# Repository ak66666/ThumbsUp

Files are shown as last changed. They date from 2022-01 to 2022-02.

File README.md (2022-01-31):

# 44 Keys Board "Thumbs Up!"

44-key Split Keyboard PCB with the thumb keys placed on the raised platforms.

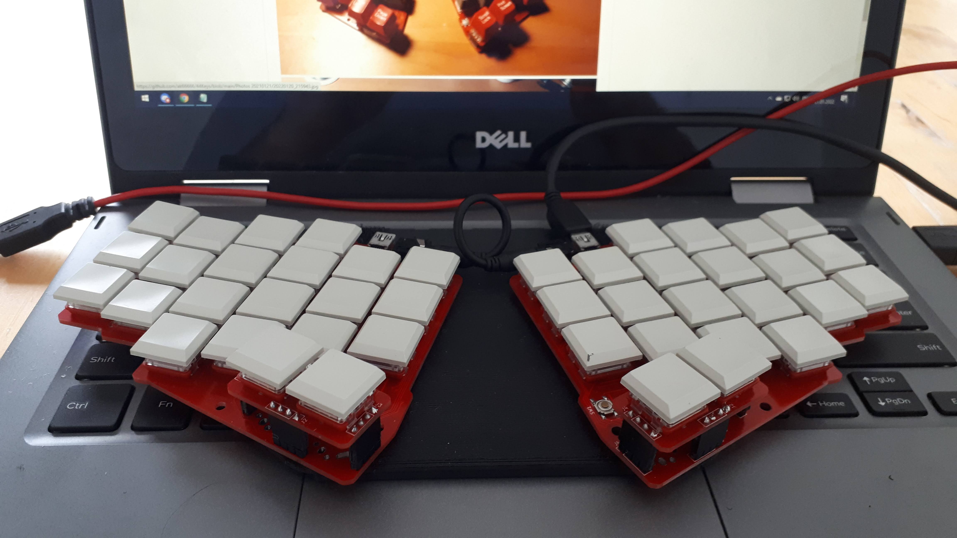
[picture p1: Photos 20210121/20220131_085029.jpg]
Kailh Choc

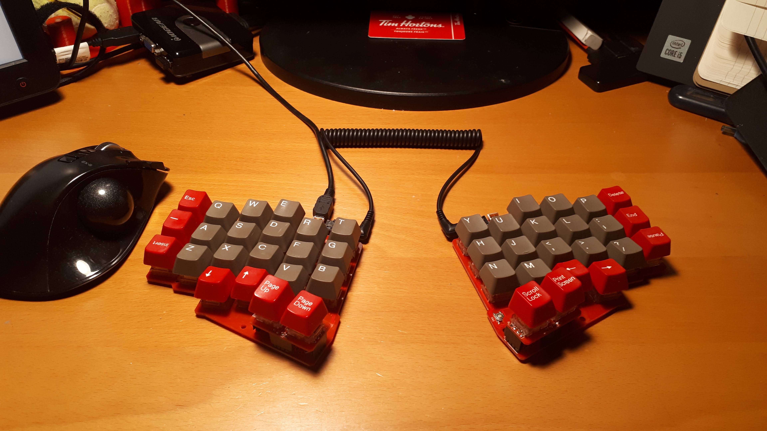
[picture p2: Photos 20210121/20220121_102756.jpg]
Matias


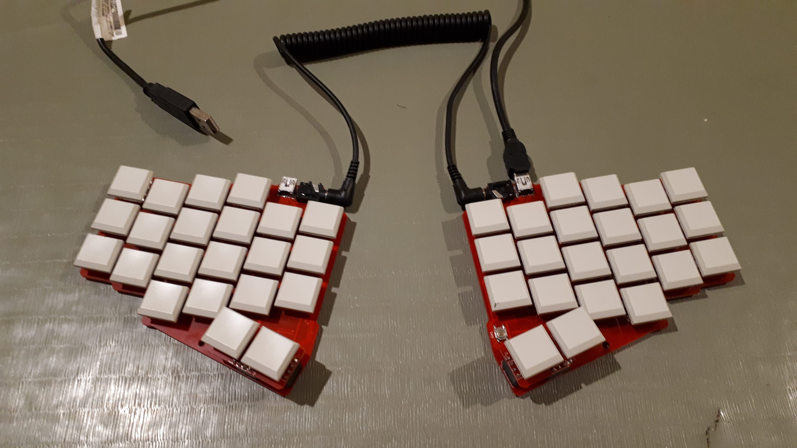
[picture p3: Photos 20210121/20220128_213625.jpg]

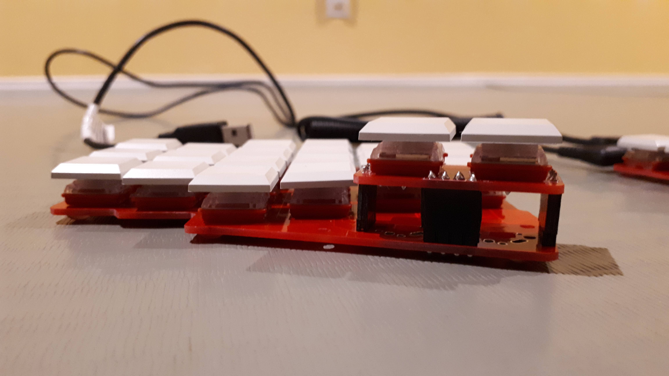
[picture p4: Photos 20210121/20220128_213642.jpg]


Ideas behind this design and layout are described here:


The naked PCB approach is borrowed from Georgi created by Germ @GBoards.ca

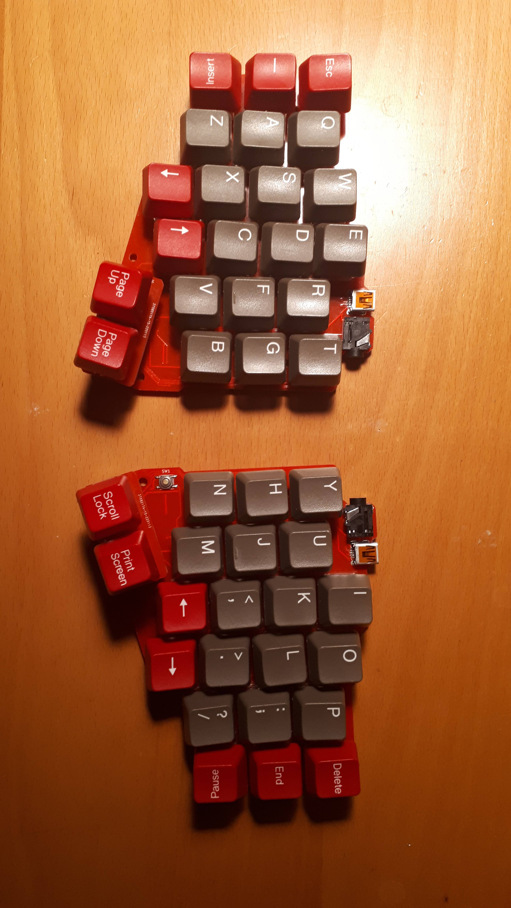
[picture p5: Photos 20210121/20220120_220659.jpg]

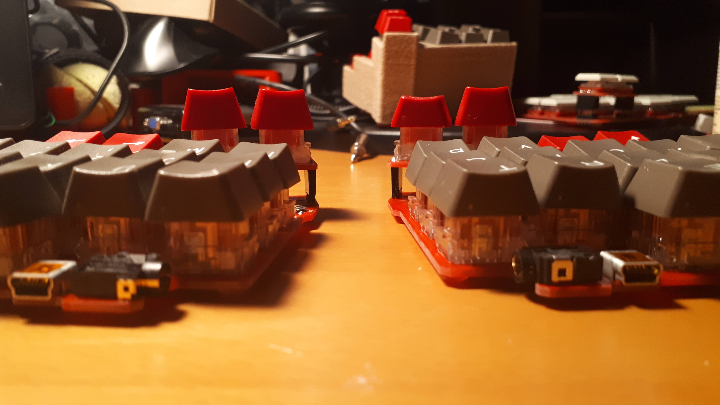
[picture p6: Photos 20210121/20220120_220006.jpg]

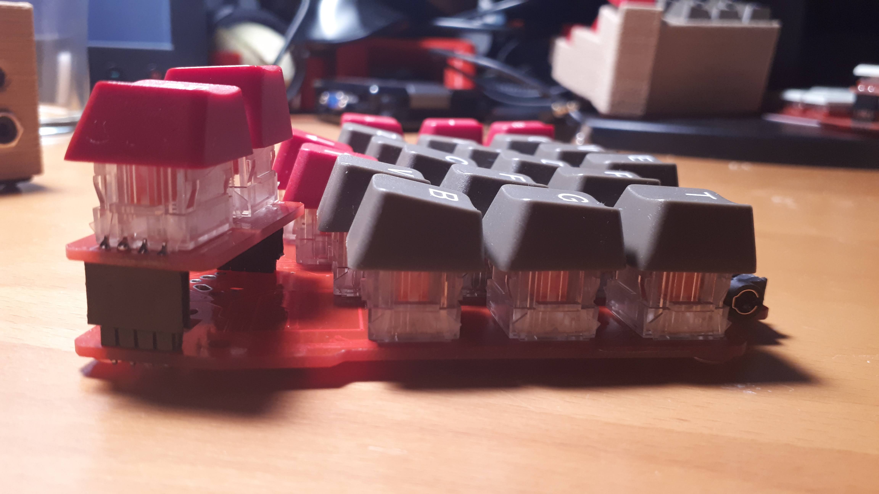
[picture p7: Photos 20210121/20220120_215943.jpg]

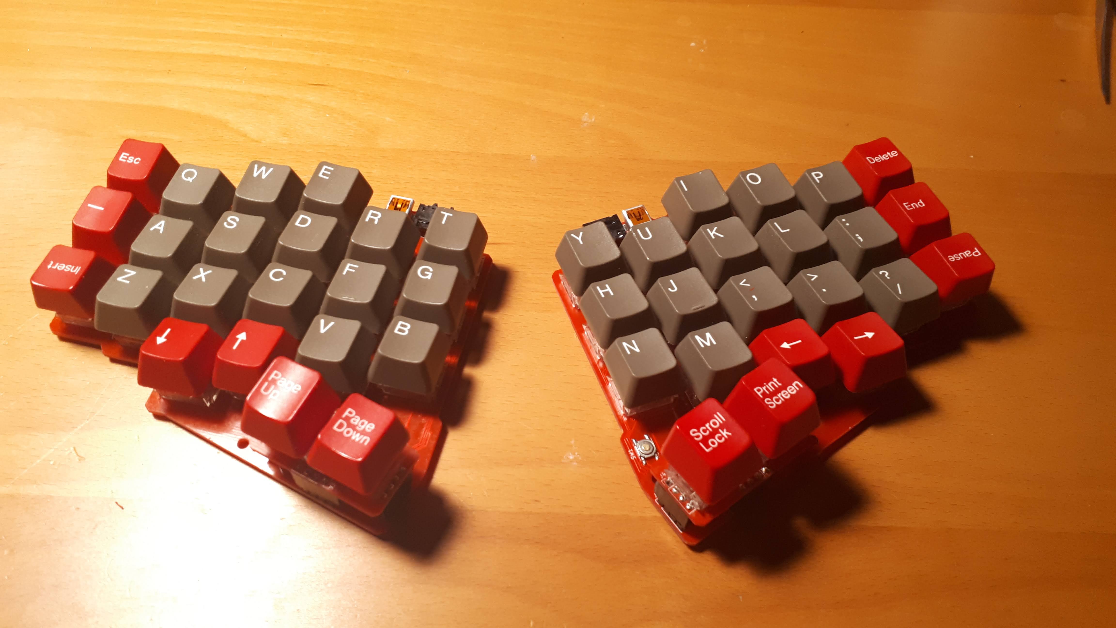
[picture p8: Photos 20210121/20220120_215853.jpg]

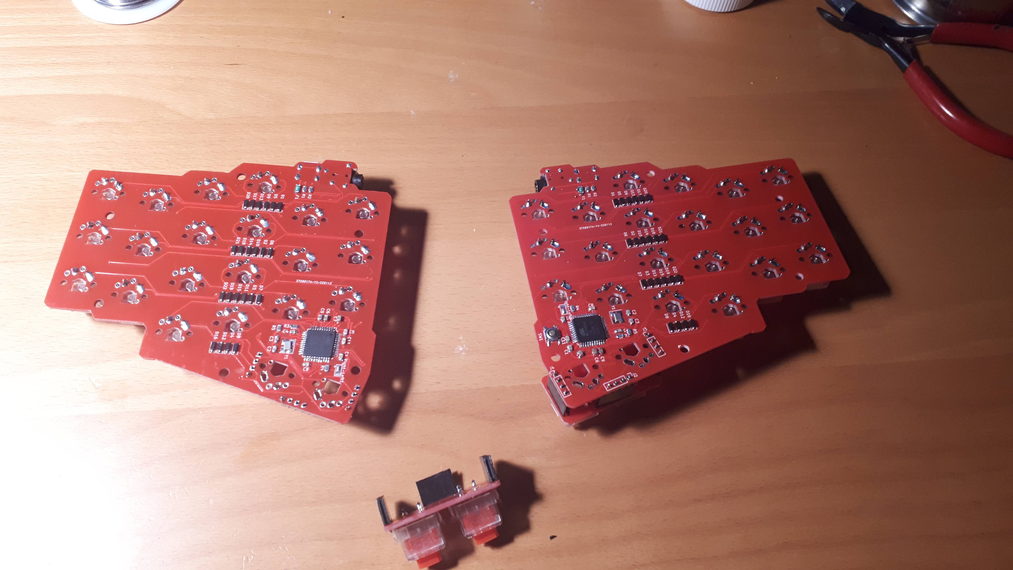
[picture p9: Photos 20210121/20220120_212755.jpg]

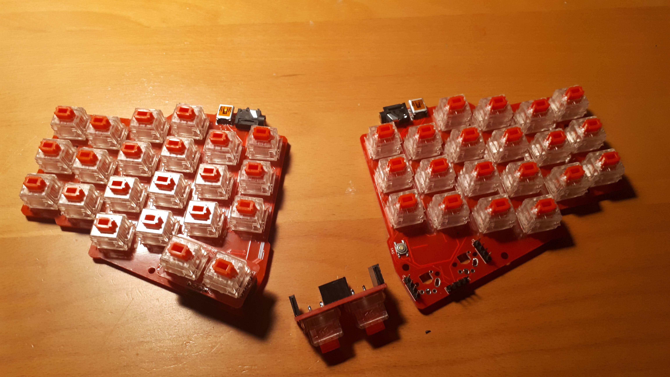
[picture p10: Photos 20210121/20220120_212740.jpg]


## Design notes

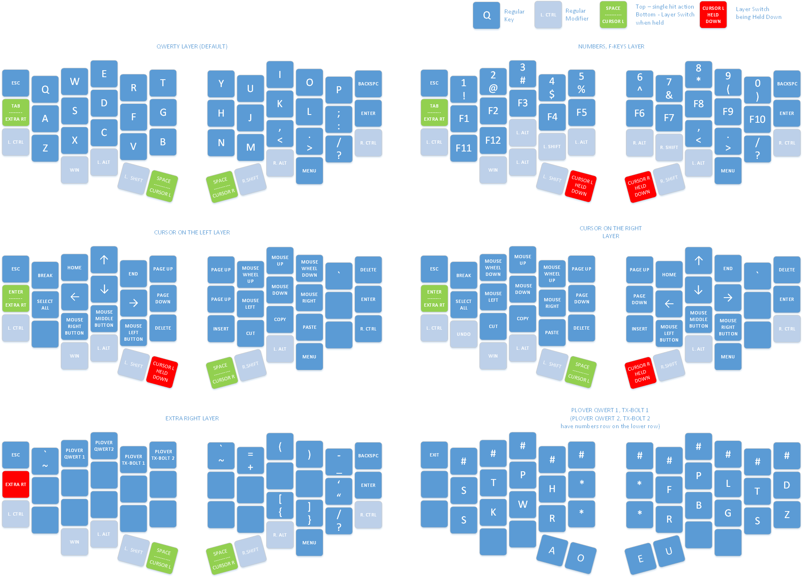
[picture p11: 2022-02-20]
Photos 20210121/44 Key Keyboard Layout.png

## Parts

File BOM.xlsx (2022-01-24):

Component | Quantity per side | Package | Sample Part | On hand | Soldered/Recoverable | Total | Qty Needed | To buy
Ceramic Capacitor, 0.1uF | 5 | 805 | 1276-2450-1-ND (https://www.digikey.com/product-detail/en/samsung-electro-mechanics/CL21B104MBCNNNC/1276-2450-1-ND/3890536) | 0 | 8 | 8 | 10 | 2
Ceramic Capacitor, 10uF | 1 | 805 | 1276-6455-1-ND (https://www.digikey.com/product-detail/en/samsung-electro-mechanics/CL21A106KOQNNNG/1276-6455-1-ND/5958083) | 5 | 1 | 6 | 2 | -4
Ceramic Capacitor, 1uF | 2 | 805 | 1276-1066-1-ND (https://www.digikey.com/product-detail/en/samsung-electro-mechanics/CL21B105KAFNNNE/1276-1066-1-ND/3889152) | 1 | 2 | 3 | 4 | 1
Ceramic Capacitor, 22pF | 2 | 805 | 1276-2605-1-ND (https://www.digikey.com/product-detail/en/samsung-electro-mechanics/CL21C220JB61PNC/1276-2605-1-ND/3890691) | 13 | 4 | 17 | 4 | -13
Diode, Generic | 22 | SOD-123 | 1N4148WTPMSCT-ND (https://www.digikey.com/product-detail/en/micro-commercial-co/1N4148W-TP/1N4148WTPMSCT-ND/717311) | 144 | 22 | 166 | 44 | -122
Polyfuse, 500mA hold, 1A trip | 1 | 1206 | 507-1803-1-ND (https://www.digikey.com/product-detail/en/bel-fuse-inc/0ZCJ0050AF2E/507-1803-1-ND/4156312) | 7 |  | 7 | 2 | -5
Resistor, 10k | 2 | 805 | P10KDACT-ND (https://www.digikey.com/product-detail/en/panasonic-electronic-components/ERA-6AEB103V/P10KDACT-ND/1465971) | 12 | 4 | 16 | 4 | -12
Resistor, 22 | 2 | 805 | P22ACT-ND (https://www.digikey.com/product-detail/en/panasonic-electronic-components/ERJ-6GEYJ220V/P22ACT-ND/87316) | 12 | 4 | 16 | 4 | -12
Low Profile Tactile Switch | 1 | 5.2x5.2mm | CKN10361CT-ND (https://www.digikey.com/product-detail/en/c-k/RS-187R05A2-DS-MT-RT/CKN10361CT-ND/2747199) | 5 | 2 | 7 | 2 | -5
ATMEGA32U4 Microcontroller | 1 | 44TQFP 10x10mm | ATMEGA32U4-AU-ND (https://www.digikey.com/product-detail/en/microchip-technology/ATMEGA32U4-AU/ATMEGA32U4-AU-ND/1914602) | 9 | 3 | 12 | 2 | -10
Molex Mini-B USB C Receptacle | 1 | Molex-0548190589 | WM3895CT-ND (https://www.digikey.com/product-detail/en/molex-llc/0548190589/WM3895CT-ND/2421963) | 6 | 2 | 8 | 2 | -6
Crystal, 16MHz | 1 | 3.2x2.5mm, 4 pad | 1253-1698-1-ND‎ (https://www.digikey.com/product-detail/en/CX3225SB16000D0GZJC1/1253-1698-1-ND/5995245/?itemSeq=264931473) | 6 | 1 | 7 | 2 | -5
Stereo Jack 3.5 mm | 1 |  | SJ-43515TS | 6 | 2 | 8 | 2 | -6
Halves to build | 2

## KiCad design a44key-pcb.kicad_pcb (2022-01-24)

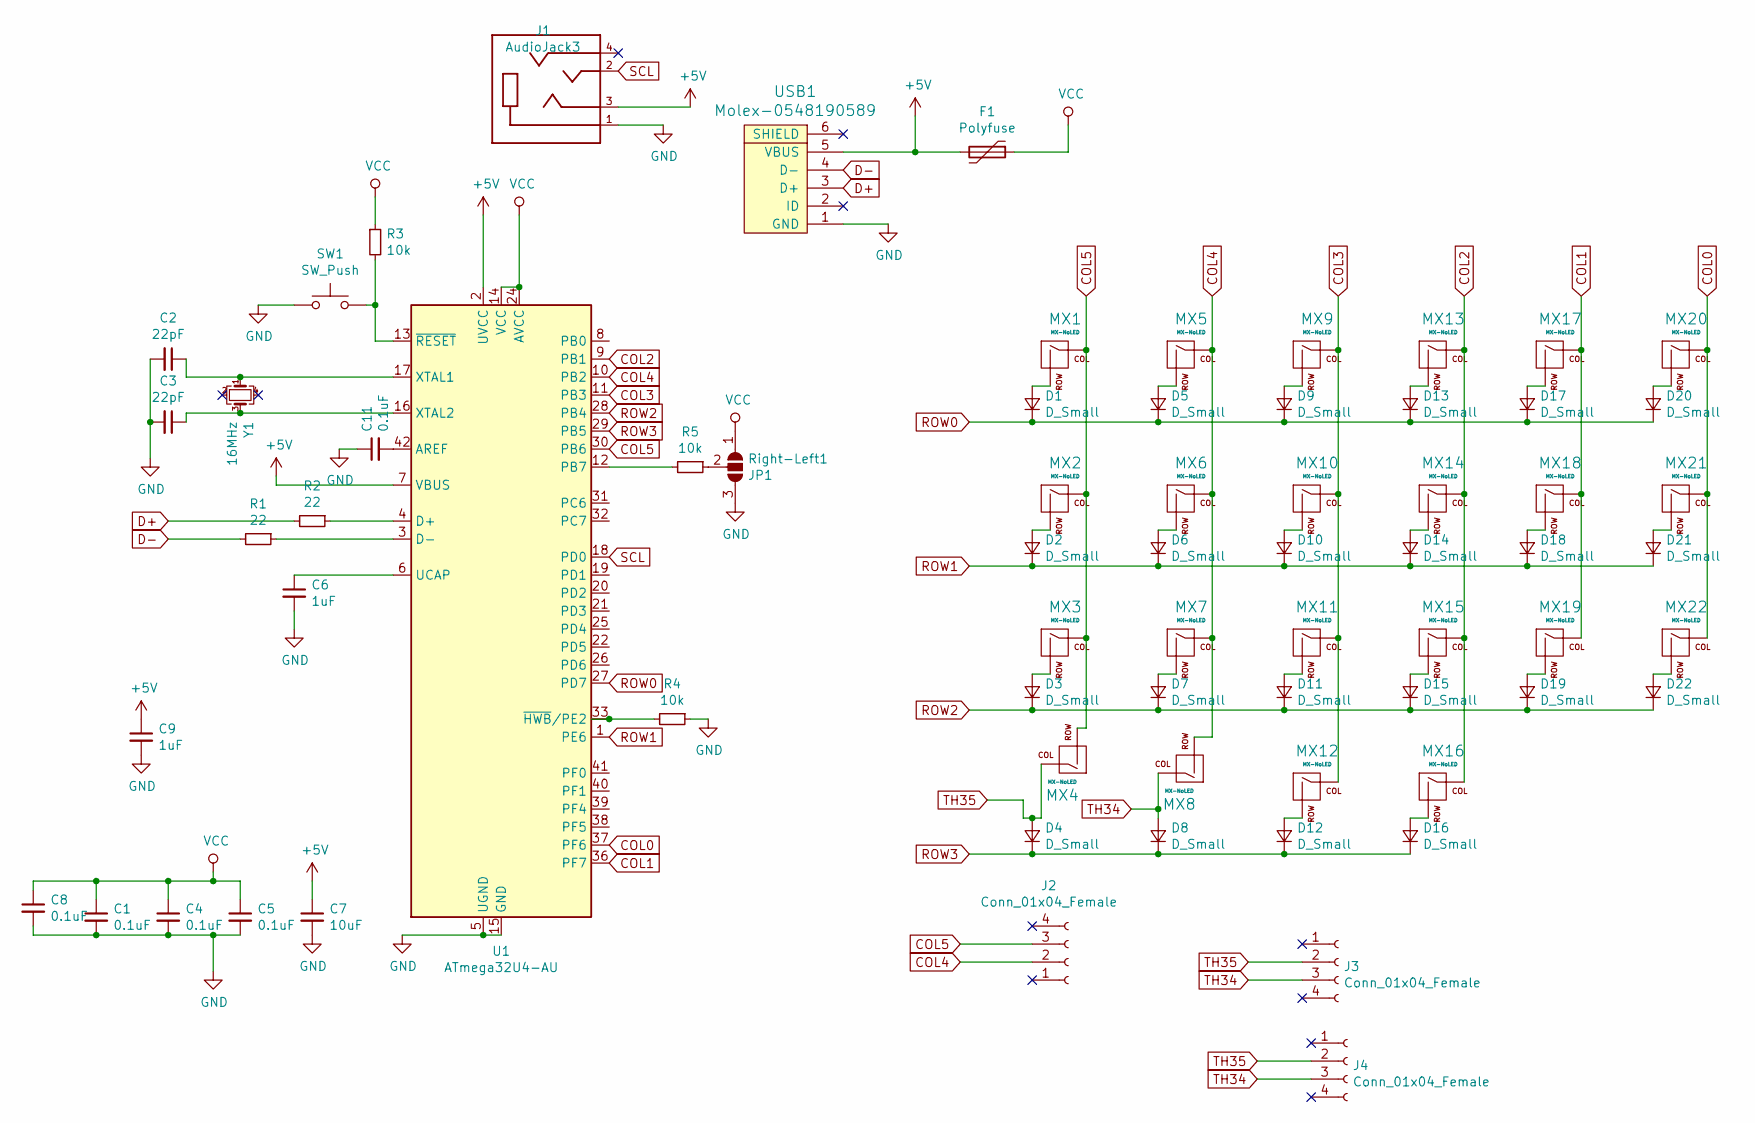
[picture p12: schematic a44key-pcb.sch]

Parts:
C1, C4, C5, C8, C11: 0.1uF; C_0805_2012Metric
C2, C3: 22pF; C_0805_2012Metric
C6, C9: 1uF; C_0805_2012Metric
C7: 10uF; C_0805_2012Metric
D1, D2, D3, D4, D5, D6, D7, D8, D9, D10, D11, D12, D13, D14, D15, D16, D17, D18, D19, D20, D21, D22: D_Small; D_SOD-123
F1: Polyfuse; Fuse_1206_3216Metric
J1: AudioJack3; CUI_SJ-43514
J2, J3, J4: Conn_01x04_Female; PinHeader_1x04_P2.54mm_Vertical
MX1, MX2, MX3, MX4, MX5, MX6, MX7, MX8, MX9, MX10, MX11, MX12, MX13, MX14, MX15, MX16, MX17, MX18, MX19, MX20, MX21, MX22: MX-NoLED; MX-Alps-Choc-X-1U-NoLED
R1, R2: 22; R_0805_2012Metric
R3, R4, R5: 10k; R_0805_2012Metric
Right-Left1: JP1; SolderJumper-3_P1.3mm_Open_Pad1.0x1.5mm
SW1: SW_Push; SKQG-1155865
U1: ATmega32U4-AU; TQFP-44_10x10mm_P0.8mm
USB1: Molex-0548190589
Y1: 16MHz; Crystal_SMD_3225-4Pin_3.2x2.5mm_HandSoldering

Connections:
+5V: C7.1, C9.1, F1.2, J1.3, U1.2 (UVCC), U1.7 (VBUS), USB1.5 (VBUS)
COL0: MX20.1 (COL), MX21.1 (COL), MX22.1 (COL), U1.37 (PF6)
COL1: MX17.1 (COL), MX18.1 (COL), MX19.1 (COL), U1.36 (PF7)
COL2: MX13.1 (COL), MX14.1 (COL), MX15.1 (COL), MX16.1 (COL), U1.9 (PB1)
COL3: MX9.1 (COL), MX10.1 (COL), MX11.1 (COL), MX12.1 (COL), U1.11 (PB3)
COL4: J2.2, MX5.1 (COL), MX6.1 (COL), MX7.1 (COL), MX8.2 (ROW), U1.10 (PB2)
COL5: J2.3, MX1.1 (COL), MX2.1 (COL), MX3.1 (COL), MX4.2 (ROW), U1.30 (PB6)
D+: R2.2, USB1.3 (D+)
D-: R1.2, USB1.4 (D-)
GND: C1.2, C2.2, C3.2, C4.2, C5.2, C6.2, C7.2, C8.2, C9.2, C11.1, J1.1, R4.1, Right-Left1.3 (B), SW1.1, U1.5 (UGND), U1.15 (GND), U1.23 (GND), U1.35 (GND), U1.43 (GND), USB1.1 (GND)
unnamed: C2.1, U1.17 (XTAL1), Y1.1
unnamed: C3.1, U1.16 (XTAL2), Y1.3
unnamed: C6.1, U1.6 (UCAP)
unnamed: C11.2, U1.42 (AREF)
unnamed: D1.2 (A), MX1.2 (ROW)
unnamed: D2.2 (A), MX2.2 (ROW)
unnamed: D3.2 (A), MX3.2 (ROW)
unnamed: D5.2 (A), MX5.2 (ROW)
unnamed: D6.2 (A), MX6.2 (ROW)
unnamed: D7.2 (A), MX7.2 (ROW)
unnamed: D9.2 (A), MX9.2 (ROW)
unnamed: D10.2 (A), MX10.2 (ROW)
unnamed: D11.2 (A), MX11.2 (ROW)
unnamed: D12.2 (A), MX12.2 (ROW)
unnamed: D13.2 (A), MX13.2 (ROW)
unnamed: D14.2 (A), MX14.2 (ROW)
unnamed: D15.2 (A), MX15.2 (ROW)
unnamed: D16.2 (A), MX16.2 (ROW)
unnamed: D17.2 (A), MX17.2 (ROW)
unnamed: D18.2 (A), MX18.2 (ROW)
unnamed: D19.2 (A), MX19.2 (ROW)
unnamed: D20.2 (A), MX20.2 (ROW)
unnamed: D21.2 (A), MX21.2 (ROW)
unnamed: D22.2 (A), MX22.2 (ROW)
unnamed: R1.1, U1.3 (D-)
unnamed: R2.1, U1.4 (D+)
unnamed: R3.2, SW1.2, U1.13 (~RESET)
unnamed: R4.2, U1.33 (~HWB~/PE2)
unnamed: R5.1, Right-Left1.2 (C)
unnamed: R5.2, U1.12 (PB7)
ROW0: D1.1 (K), D5.1 (K), D9.1 (K), D13.1 (K), D17.1 (K), D20.1 (K), U1.27 (PD7)
ROW1: D2.1 (K), D6.1 (K), D10.1 (K), D14.1 (K), D18.1 (K), D21.1 (K), U1.1 (PE6)
ROW2: D3.1 (K), D7.1 (K), D11.1 (K), D15.1 (K), D19.1 (K), D22.1 (K), U1.28 (PB4)
ROW3: D4.1 (K), D8.1 (K), D12.1 (K), D16.1 (K), U1.29 (PB5)
SCL: J1.2, U1.18 (PD0)
TH34: D8.2 (A), J3.3, J4.3, MX8.1 (COL)
TH35: D4.2 (A), J3.2, J4.2, MX4.1 (COL)
VCC: C1.1, C4.1, C5.1, C8.1, F1.1, R3.1, Right-Left1.1 (A), U1.14 (VCC), U1.24 (AVCC), U1.34 (VCC), U1.44 (AVCC)

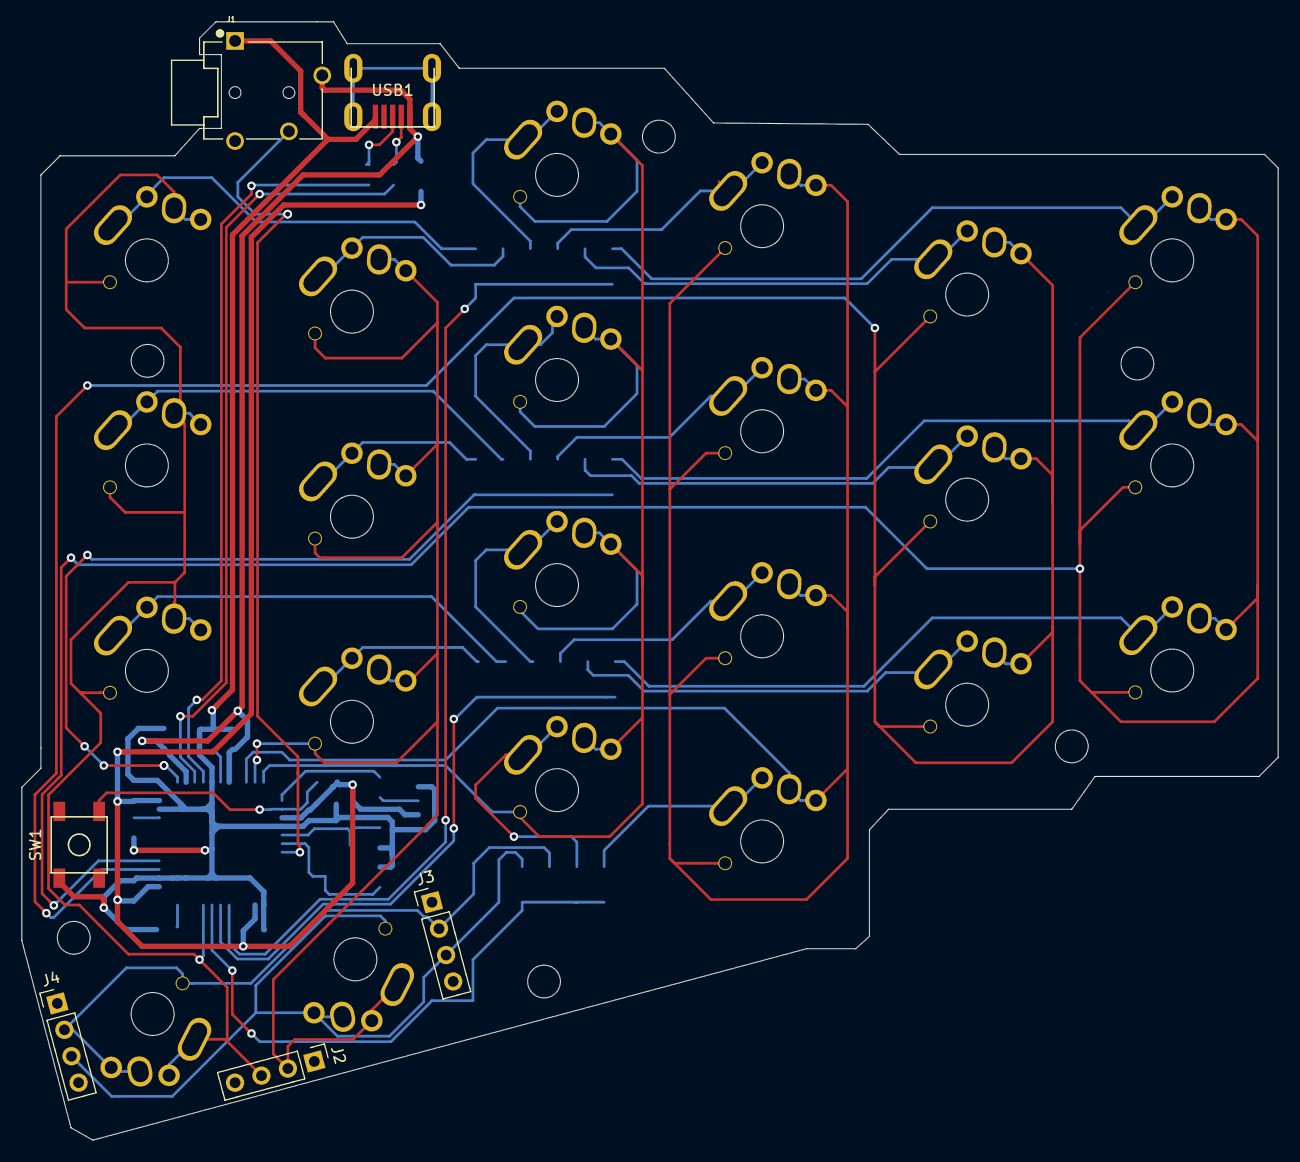
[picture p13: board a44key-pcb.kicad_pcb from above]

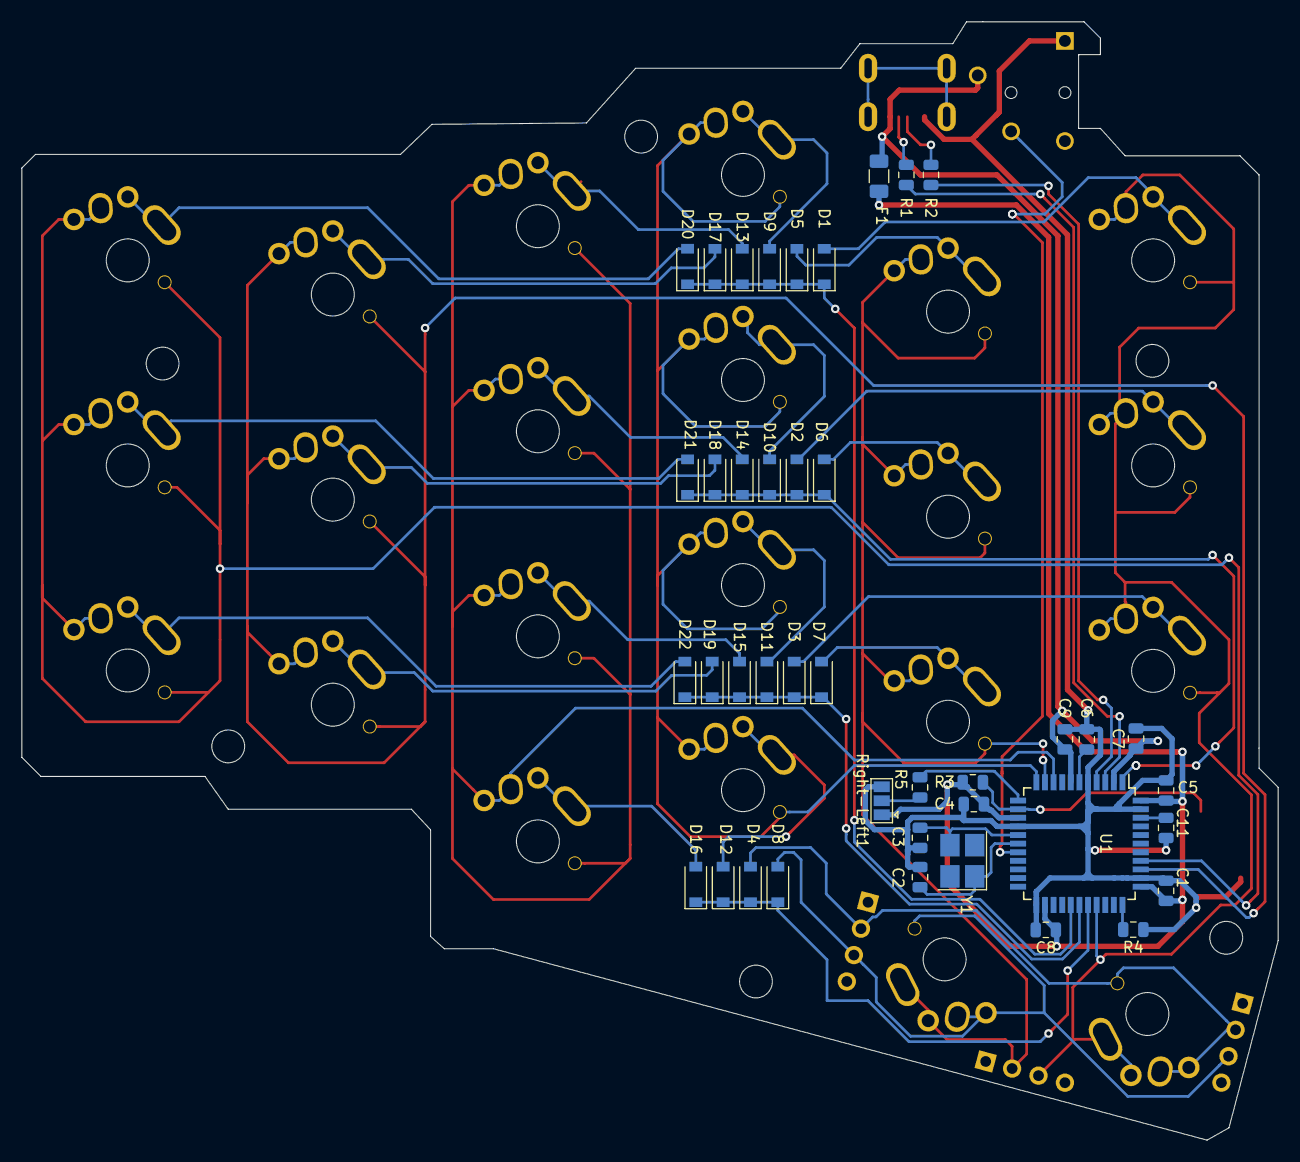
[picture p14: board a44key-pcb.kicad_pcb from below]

Board: 2 copper layers, 116.7 x 103.9 mm, 69 parts (41 on the bottom side), 48 nets.

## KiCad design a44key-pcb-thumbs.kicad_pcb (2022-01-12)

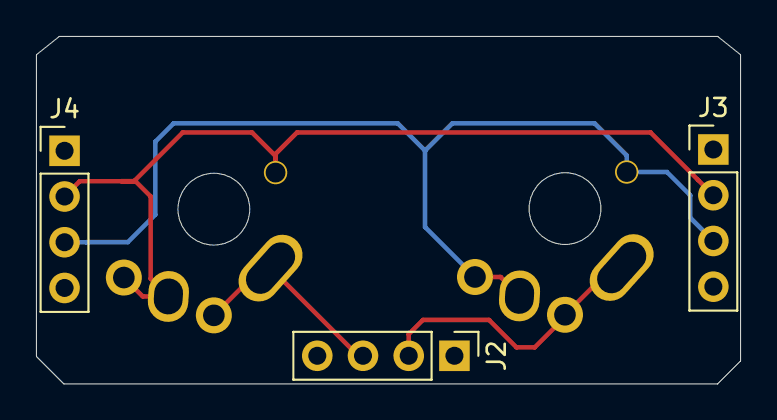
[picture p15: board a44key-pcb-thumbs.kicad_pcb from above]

Board: 2 copper layers, 39.1 x 19.3 mm, 5 parts (0 on the bottom side), 4 nets.

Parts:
J2, J3, J4: Conn_01x04_Female; PinHeader_1x04_P2.54mm_Vertical
MX4, MX8: MX-NoLED; MX-Alps-Choc-X-1U-NoLED

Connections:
COL4: J2.2, MX8.2
COL5: J2.3, MX4.2
TH34: J3.3, J4.3, MX8.1
TH35: J3.2, J4.2, MX4.1

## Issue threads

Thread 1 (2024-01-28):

STL for ThumbsUp! v2 "lift"

BigBlueHat, 2024-01-28:
There used to be an STL file on the thumbsup.shop site (which seems to currently be down) for tilting/lifting the ThumbsUp! v2 forward.

Could it be added to this repo?

Thanks for the great keyboard, @ak66666!
🎩

ak66666, 2024-01-28:
Hi,
Thank you.
Please find them here:
https://www.thingiverse.com/ak666666/designs

Thank you,
Alexander (Sasha) Karmanov
289-952-3067

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

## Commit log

2021-10-16 KiCAD project added.
    KiCAD Project created
    [a44key-pcb.kicad_pcb, a44key-pcb.sch]
2021-10-16 Submodules added
    [a44key-pcb.sch]
2021-10-18 Somewhat ready
    [a44key-pcb-B_Cu.gbl, a44key-pcb-B_Mask.gbs, a44key-pcb-B_SilkS.gbo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]
2021-10-18 Gerbers created
    [a44key-pcb-B_Cu.gbl, a44key-pcb-B_Mask.gbs, a44key-pcb-B_SilkS.gbo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]
2021-10-22 Covered with zones
    [a44key-pcb.kicad_pcb, a44key-pcb.sch]
2021-10-22 Generated Gerbers
    [a44key-pcb-B_Cu.gbl, a44key-pcb-B_Mask.gbs, a44key-pcb-B_SilkS.gbo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]
2021-11-10 Added raisers for the thumbs
    [a44key-pcb.kicad_pcb, a44key-pcb.sch]
2021-11-10 Breakout added
    [a44key-pcb.kicad_pcb]
2021-11-11 Gerbers generated
    [a44key-pcb-B_Cu.gbl, a44key-pcb-B_Mask.gbs, a44key-pcb-B_SilkS.gbo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]
2022-01-06 Added the footprint libraries
    [a44key-pcb.kicad_pcb, a44key-pcb.sch]
2022-01-07 PCB Left Hand Added
    [a44key-pcb-left-hand.kicad_pcb, a44key-pcb.kicad_pcb]
2022-01-08 PCB Thumbs Raiser Added
    [a44key-pcb-thumbs.kicad_pcb]
2022-01-14 BOM added
    [BOM.xlsx]
2022-01-24 Added parameters for the modifier to work nicelyDD
    [BOM.xlsx, a44key-pcb-left-hand.kicad_pcb, a44key-pcb.kicad_pcb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]
2022-01-24 Fixed the traces for the hand choosing jumper
    [a44key-pcb-B_Cu.gbl, a44key-pcb-B_Mask.gbs, a44key-pcb-B_SilkS.gbo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]
